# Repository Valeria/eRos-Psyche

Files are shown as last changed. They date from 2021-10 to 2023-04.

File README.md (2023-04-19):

# eRos & Psyche
### **Open Source Dildo running on the ESP32 Platform**

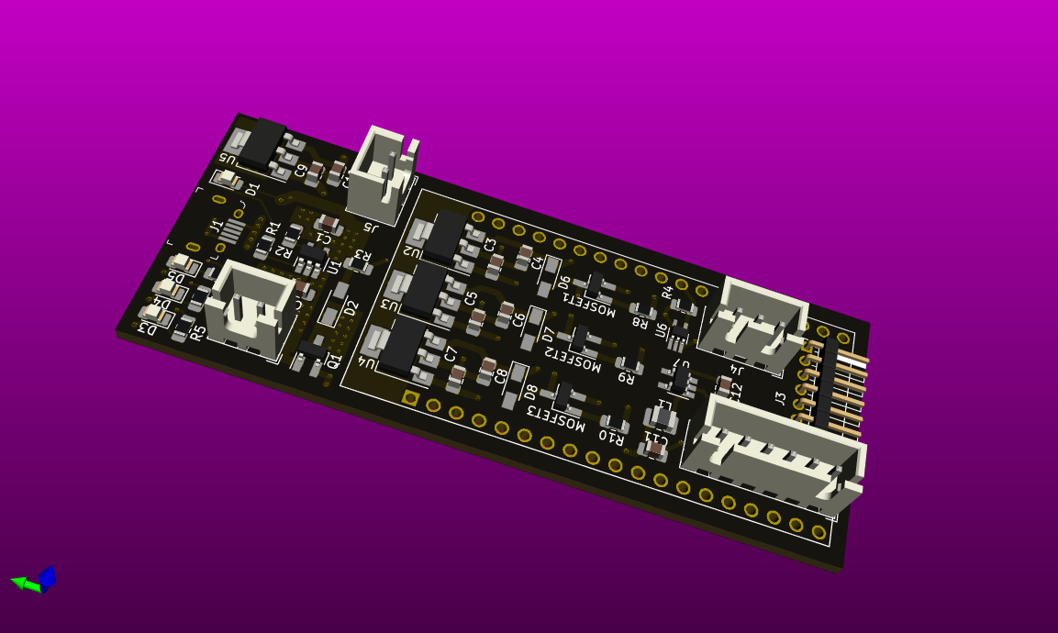
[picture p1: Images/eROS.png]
PCB! PCB

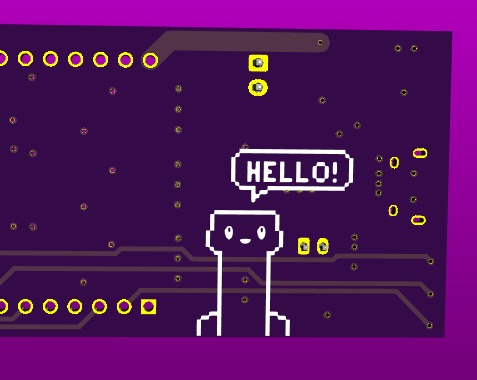
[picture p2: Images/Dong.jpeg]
Hello! Hi!

Licenses License Information

V1.0 Attaches to a **ESP32-DevKitC-V4**, **check pinout to make sure it coincides**.

It's meant to drive three (or less) **3.3v motors, max 1A per PWM output**.
Use with Li-Po or Li-Ion **3.7v nominal voltage batteries**.

Connects to a **Blynk.io** server, which can be self-hosted, otherwise, use the free Blynk Cloud server or contact me for a spot on mine.

Mobile app can be recreated by scanning the following QR code on the Blynk phone app:

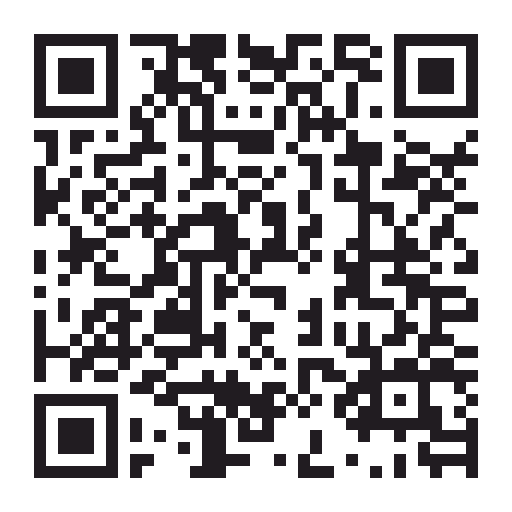
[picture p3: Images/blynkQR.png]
Blynk Project QR Scan this on Blynk app


Hardware files are in the **eRos** directory, meant to be edited on **KiCad v5.0 or higher**.

Firmware files are in the **Psyche** directory, if you open the project on PlatformIO it should load all required Arduino libraries automatically, else, here's a list:

 - shaggydog/OneButton@^1.5.0
 - ayushsharma82/AsyncElegantOTA@^2.2.5
 - ottowinter/AsyncTCP-esphome@^1.2.1
 - ottowinter/ESPAsyncWebServer-esphome@^1.2.7
 - bblanchon/ArduinoJson@^6.17.3
 - s00500/ESPUI@^2.0.0
 - khoih.prog/Blynk_Async_ESP32_BT_WF@^1.2.1
 - adafruit/Adafruit BMP280 Library@^2.4.1
 - teckel12/NewPing@^1.9.1
 - gamegine/HCSR04 ultrasonic sensor@^2.0.2
 - adafruit/Adafruit_VL53L0X@^1.1.1

Firmware.bin must be built with the **huge_app.csv** partition scheme.

Have fun!

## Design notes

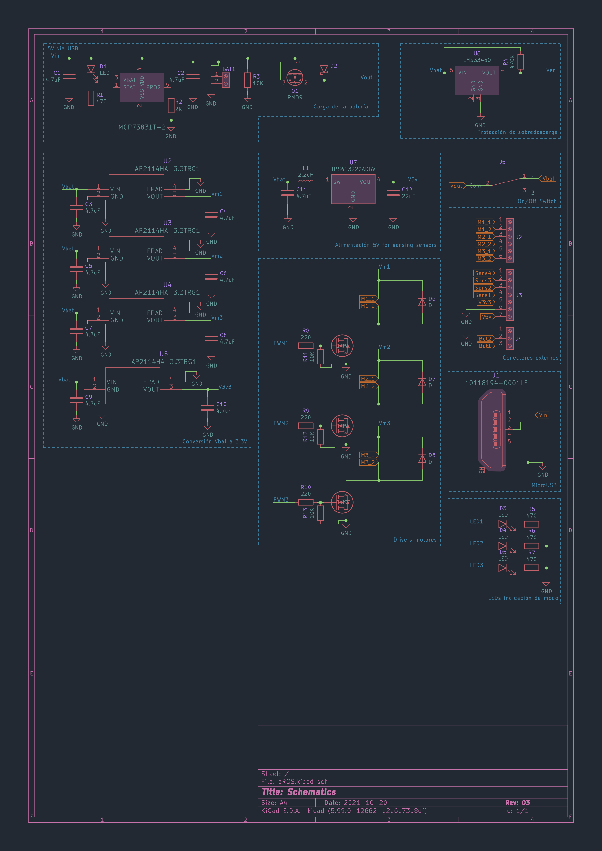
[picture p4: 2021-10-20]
Images/Schematics.png

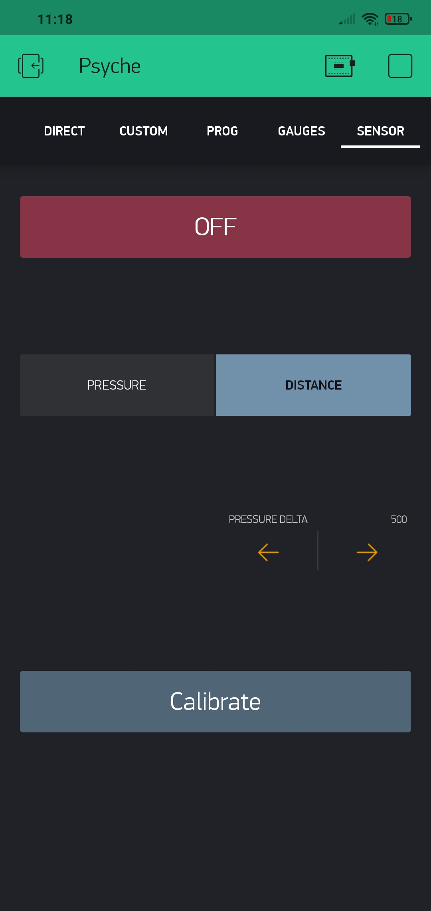
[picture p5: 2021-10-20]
Images/blynkSensor.jpg

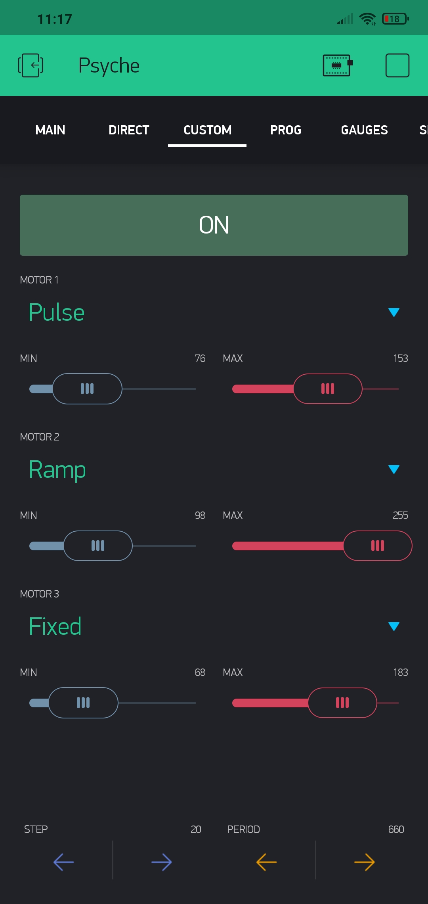
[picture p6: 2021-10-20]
Images/blynkCustom.jpg

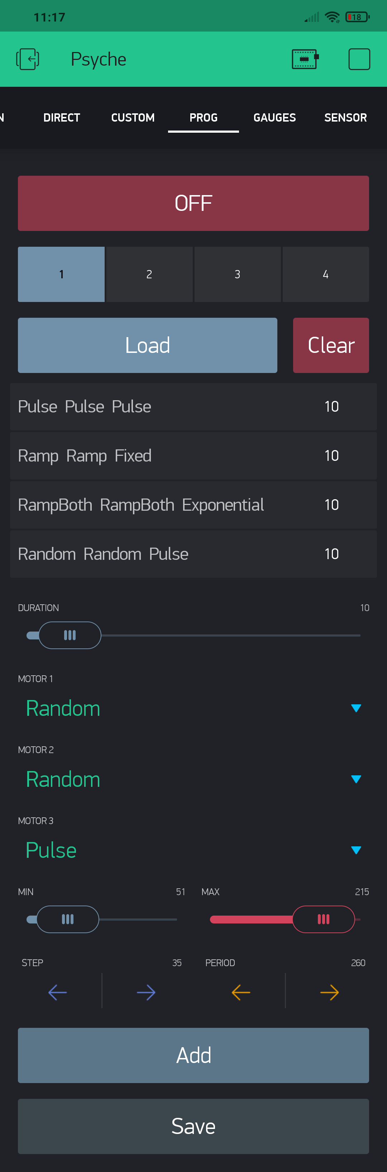
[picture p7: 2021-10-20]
Images/blynkProg.png

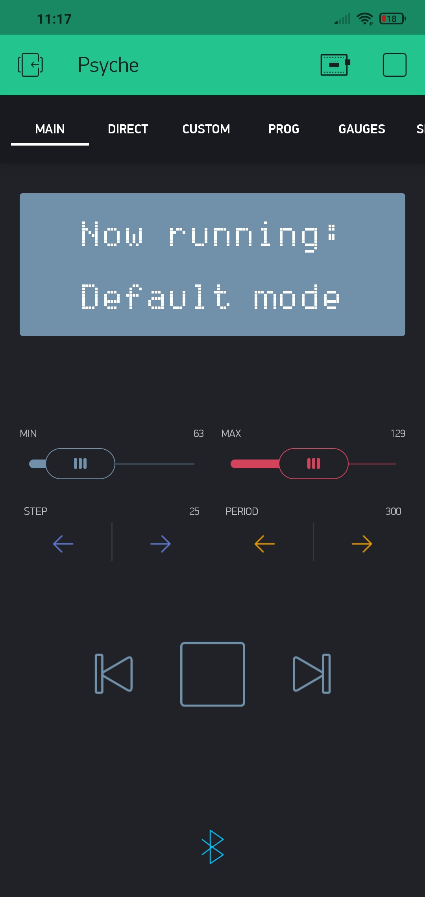
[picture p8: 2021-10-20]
Images/blynkMain.jpg

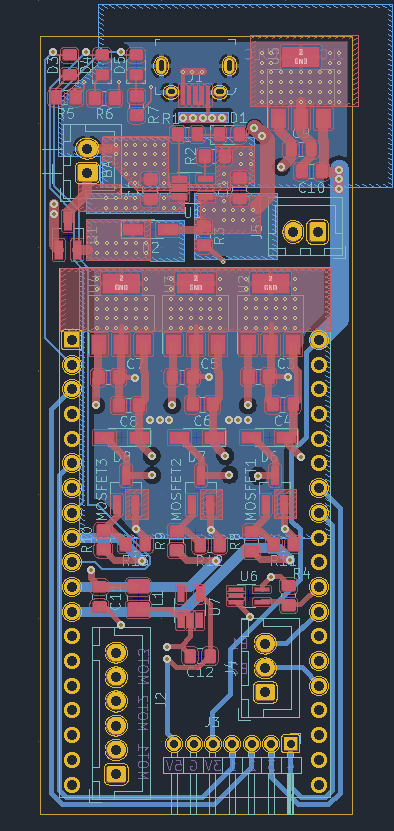
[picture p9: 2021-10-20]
Images/PCB.png

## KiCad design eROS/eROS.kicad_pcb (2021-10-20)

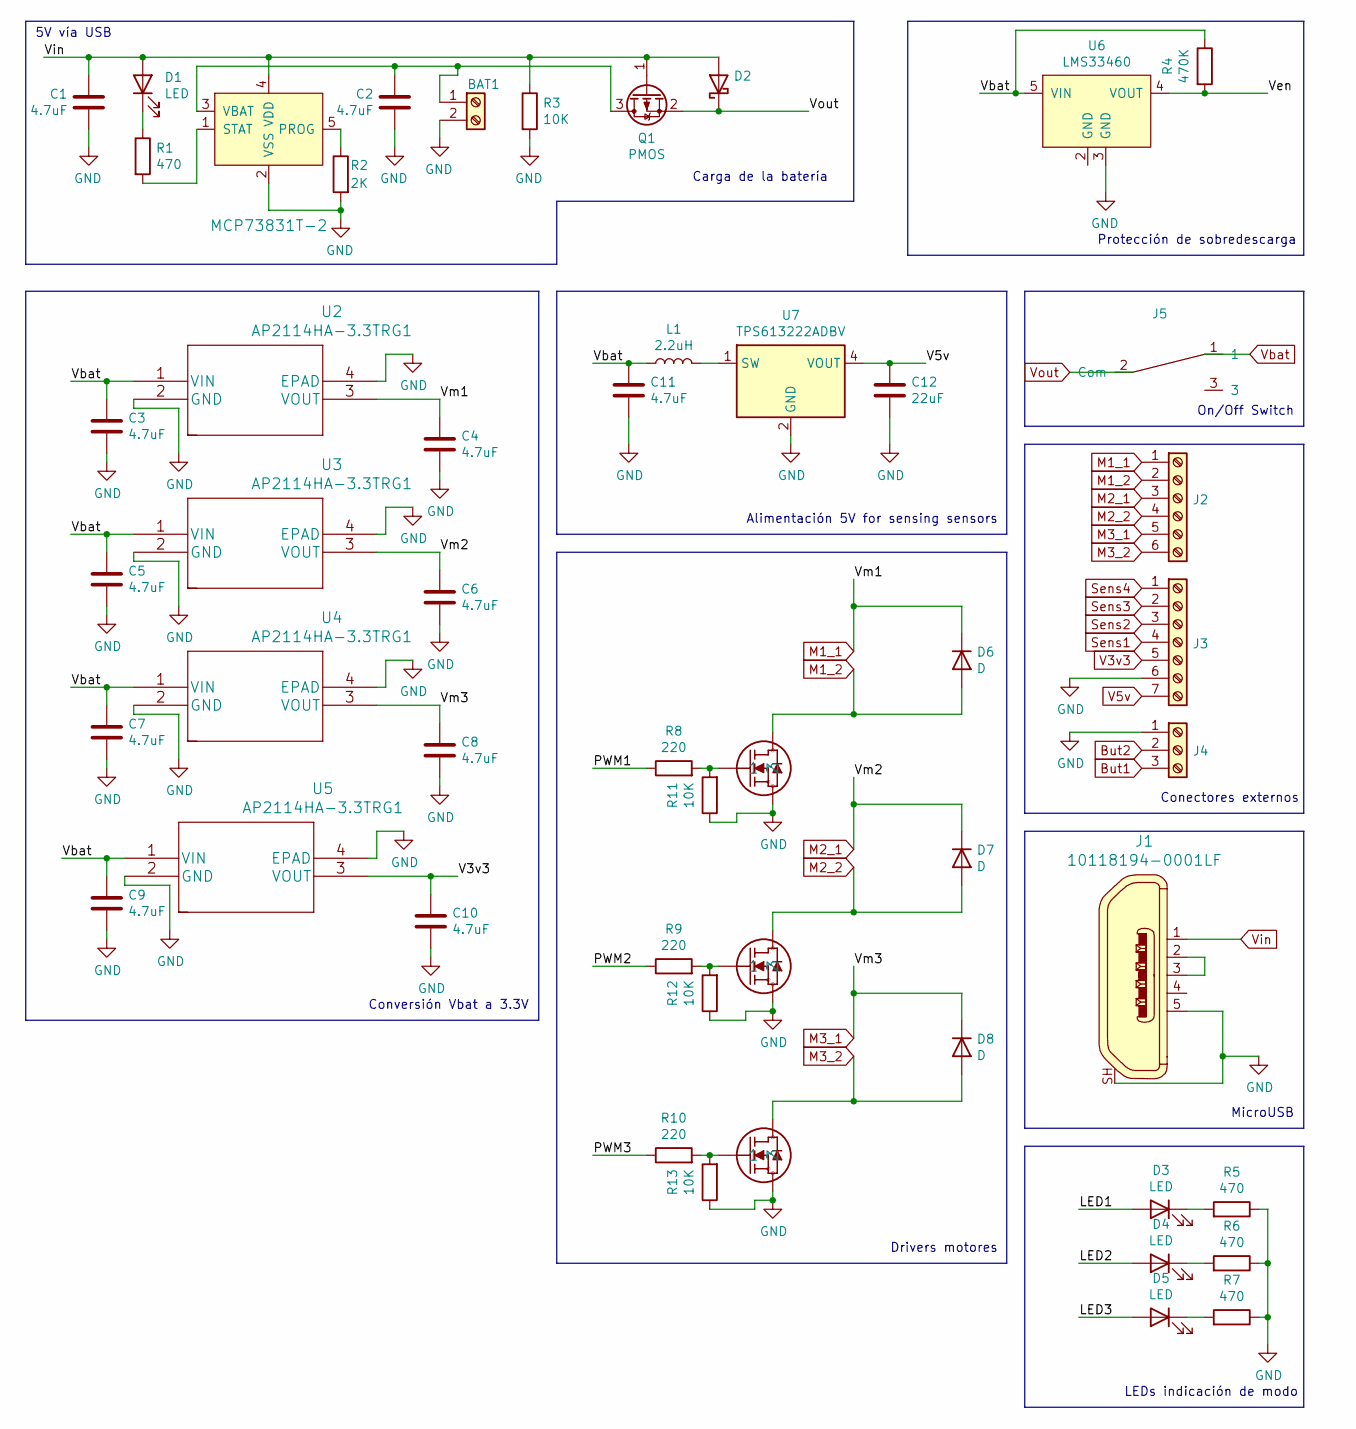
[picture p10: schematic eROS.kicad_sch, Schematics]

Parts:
BAT1: Screw_Terminal_01x02; JST_XH_B2B-XH-A_1x02_P2.50mm_Vertical
C1, C2, C3, C4, C5, C6, C7, C8, C9, C10, C11: 4.7uF; C_0805_2012Metric_Pad1.18x1.45mm_HandSolder
C12: 22uF; C_0805_2012Metric_Pad1.18x1.45mm_HandSolder
D1, D3, D4, D5: LED; LED_0805_2012Metric_Pad1.15x1.40mm_HandSolder
D2: D_Schottky; Nexperia_CFP3_SOD-123W_Handsolder
D6, D7, D8: D; Nexperia_CFP3_SOD-123W_Handsolder
J1: 10118194-0001LF; USB_Micro_B_Female_10118194-0001LF_HandSolder; MPN 10118194-0001LF; Digi-Key_PN 609-4618-1-ND
J2: Screw_Terminal_01x06; JST_XH_B6B-XH-A_1x06_P2.50mm_Vertical
J3: Screw_Terminal_01x07; PinHeader_1x07_P2.00mm_Horizontal
J4: Screw_Terminal_01x03; JST_XH_B3B-XH-A_1x03_P2.50mm_Vertical
J5: MiniSlideSwitch; JST_XH_B2B-XH-A_1x02_P2.50mm_Vertical
L1: 2.2uH; L_1008_2520Metric_Pad1.43x2.20mm_HandSolder
MOSFET1, MOSFET2, MOSFET3: IRLML6246TRPBF; SOT-23_Handsoldering
Q1: PMOS; SOT-23_Handsoldering
R1, R5, R6, R7: 470; R_0805_2012Metric_Pad1.20x1.40mm_HandSolder
R2: 2K; R_0805_2012Metric_Pad1.20x1.40mm_HandSolder
R3, R11, R12, R13: 10K; R_0805_2012Metric_Pad1.20x1.40mm_HandSolder
R4: 470K; R_0805_2012Metric_Pad1.20x1.40mm_HandSolder
R8, R9, R10: 220; R_0805_2012Metric_Pad1.20x1.40mm_HandSolder
U1: MCP73831T-2; SOT-23-5_HandSoldering; MPN MCP73831T-2DCI/OT; Digi-Key_PN MCP73831T-2DCI/OTCT-ND
U2, U3, U4, U5: AP2114HA-3.3TRG1; SOT-223-3_TabPin2
U6: LMS33460; SOT-353_SC-70-5_Handsoldering; mpn LMS33460
U7: TPS613222ADBV; SOT-23-5_HandSoldering

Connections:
/LED1: D3.2 (A)
/LED2: D4.2 (A)
/LED3: D5.2 (A)
/PWM1: R8.1
/PWM2: R9.1
/PWM3: R10.1
/Ven: R4.2, U6.4 (VOUT)
But1: J4.3
But2: J4.2
GND: BAT1.2, C1.2, C2.2, C3.2, C4.2, C5.2, C6.2, C7.2, C8.2, C9.2, C10.2, C11.2, C12.2, J1.5, J1.SH, J3.6, J4.1, MOSFET1.2, MOSFET2.2, MOSFET3.2, R2.2, R3.2, R5.1, R6.1, R7.1, R11.1, R12.1, R13.1, U1.2 (VSS), U2.2 (GND), U2.4 (EPAD), U3.2 (GND), U3.4 (EPAD), U4.2 (GND), U4.4 (EPAD), U5.2 (GND), U5.4 (EPAD), U6.3 (GND), U7.2 (GND)
M1_1: C4.1, D6.1 (K), J2.1, U2.3 (VOUT)
M1_2: D6.2 (A), J2.2, MOSFET1.3
M2_1: C6.1, D7.1 (K), J2.3, U3.3 (VOUT)
M2_2: D7.2 (A), J2.4, MOSFET2.3
M3_1: C8.1, D8.1 (K), J2.5, U4.3 (VOUT)
M3_2: D8.2 (A), J2.6, MOSFET3.3
unnamed: BAT1.1, C2.1, Q1.3 (D), U1.3 (VBAT)
unnamed: D1.1 (K), R1.1
unnamed: D3.1 (K), R5.2
unnamed: D4.1 (K), R6.2
unnamed: D5.1 (K), R7.2
unnamed: J1.2, J1.3
unnamed: L1.2, U7.1 (SW)
unnamed: MOSFET1.1, R8.2, R11.2
unnamed: MOSFET2.1, R9.2, R12.2
unnamed: MOSFET3.1, R10.2, R13.2
unnamed: R1.2, U1.1 (STAT)
unnamed: R2.1, U1.5 (PROG)
Sens1: J3.4
Sens2: J3.3
Sens3: J3.2
Sens4: J3.1
V3v3: C10.1, J3.5, U5.3 (VOUT)
V5v: C12.1, J3.7, U7.4 (VOUT)
Vbat: C3.1, C5.1, C7.1, C9.1, C11.1, J5.1, L1.1, R4.1, U2.1 (VIN), U3.1 (VIN), U4.1 (VIN), U5.1 (VIN), U6.5 (VIN)
Vin: C1.1, D1.2 (A), D2.2 (A), J1.1, Q1.1 (G), R3.1, U1.4 (VDD)
Vout: D2.1 (K), J5.2 (Com), Q1.2 (S)

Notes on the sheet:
5V vía USB
Conversión Vbat a 3.3V
Carga de la batería
Alimentación 5V for sensing sensors
Drivers motores
Protección de sobredescarga
LEDs indicación de modo
Conectores externos
On/Off Switch
MicroUSB

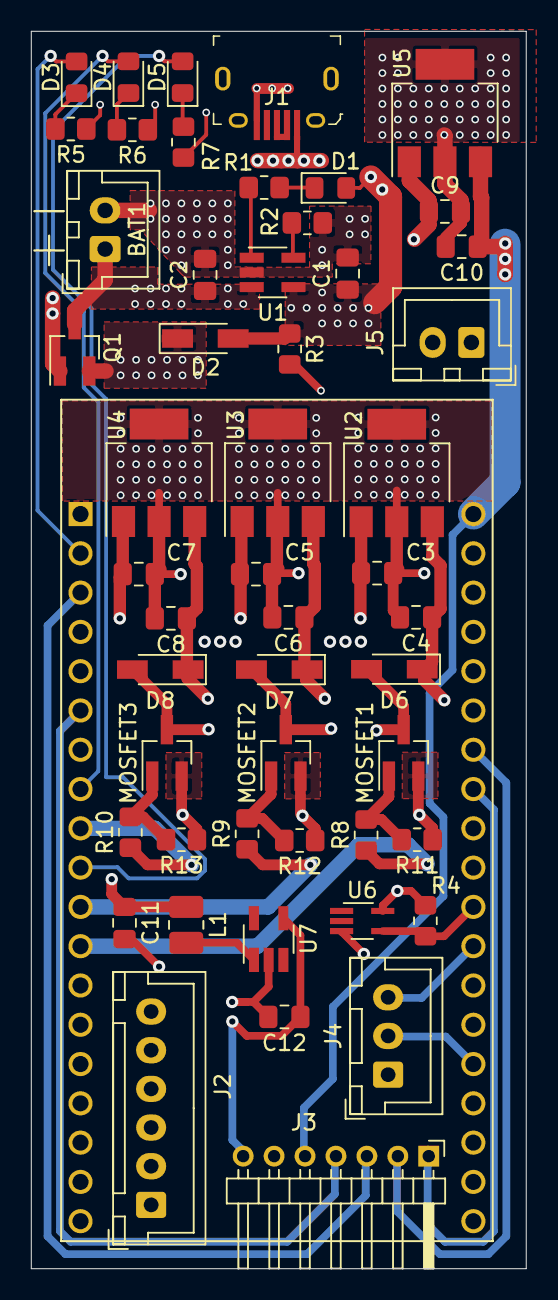
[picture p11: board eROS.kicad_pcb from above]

Board: 4 copper layers, 32.0 x 80.0 mm, 51 parts (0 on the bottom side), 25 nets.

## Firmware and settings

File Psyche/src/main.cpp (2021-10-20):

/********************************************************
  
  Based on code examples built by Khoi Hoang
  https://github.com/khoih-prog/Blynk_Async_ESP32_BT_WF
  which are licensed under MIT license.
     
 *******************************************************/

#include "defines.h"
#include "Credentials.h"
#include "dynamicParams.h"
#include "Arduino.h"
#include "OneButton.h"
#include "ArduinoJson.h"
#include "FS.h"
#include "SPIFFS.h"
#include "Adafruit_BMP280.h"
#include "Wire.h"
//#include "NewPing.h"
//#include <HCSR04.h>
#include "Adafruit_VL53L0X.h"

Adafruit_VL53L0X lox = Adafruit_VL53L0X();

// Setup Buttons
OneButton button1(14, true, true);
OneButton button2(13, true, true);

// LEDs
const int led[3] = {5, 19, 23};

// Sensors
const int sensor[4] = {21, 22, 32, 33};

// Ven: low battery signal

#define vEnableEnabled false // Enables the usage of the undervoltage detector
const int Ven = 27;
const int trytry = 0;

// PWM integers
int freq = 10000; // 10 Khz
int motorChannel[3] = {0, 1, 2};
int resolution = 8;                // 2^8 = 256 possible values
const int motor[3] = {16, 17, 18}; // Motors GPIO

// Pattern integers
int next = 0;
int lastNext = 1;
int vmax = 200;
int vmin = 30;
int step = 25;
char vminC[3], vmaxC[3], nextC[3], stepC[3], periodC[3]; // Will be required for Blynk LCD Widget
unsigned long period = 250;
unsigned long currentTime = 0;
unsigned long lastTime = 0;
int seq = 0;
int seq2 = 0;
int now = 0;

// Blynk custom pattern integers
int customMode = 0;
unsigned long lastTimeCustom[3] = {0, 0, 0};
unsigned long currentTimeCustom[3] = {0, 0, 0};
unsigned long stepCustom = 25;
unsigned long periodCustom = 200;
int vminCustom[3] = {30, 30, 30};
int vmaxCustom[3] = {255, 255, 255};
int nowCustom[3] = {0, 0, 0};
int nextCustom[3] = {0, 0, 0};
int seqCustom[3] = {0, 0, 0};
int seq2Custom[3] = {0, 0, 0};
int kCustom[3] = {1, 1, 1};

// Blynk sensor mode integers
int sensorMode = 0; // Are we in sensor mode?
int x, y, z = 0;    // We be floating in space (Gravity sensor integers)

// Blynk direct control integers
int directControl = 0; // Are we being direct controlled? (Can't assume this)
int sliderjoy = 1;     // Assume direct control via sliders (1) or joystick (2).
int joyX = 0;
int joyY = 0;

// Patterns list
#include <patterns.h>
int maxpatterns = 6; // Number of actual patterns used

// Function to set motor PWM settings to correct pattern values
// also a list of patterns currently in use
void callPattern(int k)
{
  switch (k)
  {
  case 0:
    fixedAll(0);
    break;
  case 1:
    fixedAll(vmax);
    break;
  case 2:
    pulse(vmin, vmax);
    break;
  case 3:
    ramp(vmin, vmax, step);
    break;
  case 4:
    rampBoth(vmin, vmax, step);
    break;
  case 5:
    sharpRamp(seq);
    break;
  case 6:
    randi(vmin, vmax);
    break;
  default:
    break;
  }
}

// Will be called when Button1 is clicked a single time
void Click1()
{
  next += 1;
  if (next > maxpatterns)
    next = 1; // Loop back if over range
} // Click1

// Will be called when Button2 is clicked a single time.
void Click2()
{
  next -= 1;
  if (next < 1)
    next = maxpatterns; // Loop back if over range
} // Click2

// Will be called when Button1 is held.
void HODL1()
{
  if (digitalRead(13) == LOW)
    next = 0;
} // HODL1

// Will be called when Button2 is held.
void HODL2()
{
  if (digitalRead(14) == LOW)
    next = 0;
} // HODL2

// Will be called when Button1 is clicked twice.
void ClickDouble1()
{
  vmax += 25;
  vmax = constrain(vmax, vmin, 255);
  //callPattern(next);
} // ClickDouble1

// Will be called when Button2 is clicked twice.
void ClickDouble2()
{
  vmax -= 25;
  vmax = constrain(vmax, vmin, 255);
  //callPattern(next);
} // ClickDouble2

bool USE_BLE = true;
long timePreviousMeassure = 0;

#include "blynk.h"
#include "table.h"

#define WIFI_BLE_SELECTION_PIN 14 //Pin D14 mapped to pin GPIO14/HSPI_SCK/ADC16/TOUCH6/TMS of ESP32

BlynkTimer timer;

#include <Ticker.h>
Ticker led_ticker;

#define BLYNK_PIN_FORCED_CONFIG V100 // Pin to access web configuration portal

#include <asyncSetup.h>
#include "sensor.h"

void setup()
{
  // Initialize PWM
  ledcSetup(motorChannel[0], freq, resolution);
  ledcAttachPin(motor[0], motorChannel[0]);
  ledcSetup(motorChannel[1], freq, resolution);
  ledcAttachPin(motor[1], motorChannel[1]);
  ledcSetup(motorChannel[2], freq, resolution);
  ledcAttachPin(motor[2], motorChannel[2]);

  ledcWrite(motorChannel[0], 0);
  ledcWrite(motorChannel[1], 0);
  ledcWrite(motorChannel[2], 0);

  // Initialize serial console
  Serial.begin(115200);
  /*while (!Serial)
    ;

  //delay(200);
  */

  setCpuFrequencyMhz(80); // To lower power usage, default 240Mhz isn't required for this application

  SPIFFS.begin();

  pinMode(WIFI_BLE_SELECTION_PIN, INPUT_PULLUP);
  //pinMode(WIFI_BLE_SELECTION_PIN, INPUT);

  // Set Timer to update gauges
  gaugeTimer.setInterval(1000L, gauges);

  // LEDs
  //pinMode(led[1], OUTPUT);
  //pinMode(led[2], OUTPUT);
  //pinMode(led[3], OUTPUT);

  // Sensors
  //pinMode(sensor[1], OUTPUT);
  //pinMode(sensor[2], INPUT);
  //pinMode(sensor[3], INPUT);
  //pinMode(sensor[4], INPUT); //Commented out for usage as capacitive pin

  // Ven: low battery signal
  pinMode(Ven, INPUT);

  // Attach button clicks to functions
  button1.attachClick(Click1);
  button1.attachDoubleClick(ClickDouble1);
  button1.attachLongPressStart(HODL1);
  button2.attachClick(Click2);
  button2.attachDoubleClick(ClickDouble2);
  button2.attachLongPressStart(HODL2);

// Pressure sensor
/*#if sensorsEnabled
  bmpSetup();
#endif
*/

#if BLYNK_USE_BLE_ONLY
  Blynk_BLE.setDeviceName(BLE_Device_Name);

#if ESP32_BLE_WF_DEBUG
  Serial.println(F("Blynk_BLE begin"));
#endif

  Blynk_BLE.begin(auth);
#else
  //if (digitalRead(WIFI_BLE_SELECTION_PIN) == HIGH)
    if (trytry == 1)
  {
    USE_BLE = false;
    Serial.println(F("Using Wi-Fi"));
#if USE_BLYNK_WM
    // Set config portal SSID and Password
    Blynk.setConfigPortal("eRos-ConfigPortal", "123456789");
    // Set config portal IP address
    Blynk.setConfigPortalIP(IPAddress(192, 168, 232, 1));

    // Set config portal channel, default = 1. Use 0 => random channel from 1-13 to avoid conflict
    Blynk_WF.setConfigPortalChannel(0);

    // Set static IP + DNS
    Blynk.setSTAStaticIPConfig(IPAddress(192, 168, 2, 232), IPAddress(192, 168, 2, 1), IPAddress(255, 255, 255, 0));

#if USING_CUSTOMS_STYLE
    Blynk.setCustomsStyle(NewCustomsStyle);
#endif

#if USING_CUSTOMS_HEAD_ELEMENT
    Blynk.setCustomsHeadElement("<style>html{filter: invert(10%);}</style>");
#endif

#if USING_CORS_FEATURE
    Blynk.setCORSHeader("Your Access-Control-Allow-Origin");
#endif

    //////////////////////////////////////////////

    // Use this to default DHCP hostname to ESP8266-XXXXXX or ESP32-XXXXXX
    //Blynk.begin();
    // Use this to personalize DHCP hostname (RFC952 conformed)
    // 24 chars max,- only a..z A..Z 0..9 '-' and no '-' as last char
    //Blynk.begin("ESP32-BLE-WM");

    Blynk_WF.begin(BLE_Device_Name);
#else
    //Blynk_WF.begin(auth, ssid, pass);
#if ESP32_BLE_WF_DEBUG
    Serial.println(F("Not USE_BLYNK_WM: Blynk_WF begin"));
#endif
    Blynk_WF.begin(auth, ssid, pass, cloudBlynkServer.c_str(), BLYNK_SERVER_HARDWARE_PORT);
#endif
  }
  else
  {
    USE_BLE = true;
    Serial.println(F("Using BLE"));
    Blynk_BLE.setDeviceName(BLE_Device_Name);
#if USE_BLYNK_WM
    if (Blynk_WF.getBlynkBLEToken() == NO_CONFIG) //String("blank"))
    {
      Serial.println(F("No valid stored BLE auth. Must run WiFi and enter config portal"));
      USE_BLE = false;

#if ESP32_BLE_WF_DEBUG
      Serial.println(F("USE_BLYNK_WM: No BLE Token. Blynk_WF begin"));
#endif

      Blynk_WF.begin(BLE_Device_Name);
    }
    String BLE_auth = Blynk_WF.getBlynkBLEToken();
#else
    String BLE_auth = auth;
#endif

    if (USE_BLE)
    {
      Serial.print(F("Connecting Blynk via BLE, using auth = "));
      Serial.println(BLE_auth);

#if ESP32_BLE_WF_DEBUG
      Serial.println(F("USE_BLE: Blynk_BLE begin"));
#endif

      Blynk_BLE.begin(BLE_auth.c_str());
    }
  }
#endif

  // Important, need to keep constant communication to Blynk Server at least once per ~25s
  // Or Blynk will lost and have to (auto)reconnect
  timer.setInterval(10000L, noticeAlive);

  /*
  if (!lox.begin()) {
    Serial.println(F("Failed to boot VL53L0X"));
  }
  */
 Wire.begin(32, 33);
}

#if (USE_BLYNK_WM && USE_DYNAMIC_PARAMETERS)
void displayCredentials()
{
  Serial.println(F("\nYour stored Credentials :"));

  for (uint16_t i = 0; i < NUM_MENU_ITEMS; i++)
  {
    Serial.print(myMenuItems[i].displayName);
    Serial.print(F(" = "));
    Serial.println(myMenuItems[i].pdata);
  }
}

void displayCredentialsInLoop()
{
  static bool displayedCredentials = false;

  if (!displayedCredentials)
  {
    for (uint16_t i = 0; i < NUM_MENU_ITEMS; i++)
    {
      if (!strlen(myMenuItems[i].pdata))
      {
        break;
      }

      if (i == (NUM_MENU_ITEMS - 1))
      {
        displayedCredentials = true;
        displayCredentials();
      }
    }
  }
}

#endif

void loop()
{
#if vEnableEnabled
  while (digitalRead(Ven) == LOW) // Do nothing until we get high voltage signal
    ;
#endif
  // Keep checking the buttons
  //button1.tick();
  //button2.tick();

#if BLYNK_USE_BLE_ONLY
  Blynk_BLE.run();
#else
  if (USE_BLE)
    Blynk_BLE.run();
  else
    Blynk_WF.run();
#endif

  // Call function to update PWM values
  if (directControl)
  {
    // We do nothin'!
  }
  else if (customMode)
  {
    callPatternCustom(kCustom[0], 0);
    callPatternCustom(kCustom[1], 1);
    callPatternCustom(kCustom[2], 2);
  }
  else if (tableMode)
  {
    nextTable();                            // Checks if we must move to the next pattern in the list
    callTable(patternList1[indexTable], 0); // Sets motors
    callTable(patternList2[indexTable], 1);
    callTable(patternList3[indexTable], 2);
  }
  else if (sensorMode)
  {
    if (sensorSelect == 1)
      sonarPattern();
    else if (sensorSelect == 2)
      bmpPattern();
    else if (sensorSelect == 3)
      capacitive();
  }
  else
    callPattern(next);

  timer.run();
  checkStatus();
  gaugeTimer.run();

#if (USE_BLYNK_WM && USE_DYNAMIC_PARAMETERS)
  displayCredentialsInLoop();
#endif
}

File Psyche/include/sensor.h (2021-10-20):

#define sensorsEnabled true
unsigned int sensorSelect = 0;
int capacitiveVal = 100;
int capacitiveThreshold = 2;
int sensorDone = 0;

// ESP32 Capacitive touch sensor

void capacitive()
{
currentTime = millis();
    if (currentTime - lastTime >= 100)
    {
        lastTime = currentTime;
        capacitiveVal = touchRead(T8); // GPIO 33
        if (capacitiveVal < capacitiveThreshold)
        {
            ledcWrite(motorChannel[0], vmax);
            ledcWrite(motorChannel[1], vmax);
            ledcWrite(motorChannel[2], vmax);
        }
        else
        {
            ledcWrite(motorChannel[0], vmin);
            ledcWrite(motorChannel[1], vmin);
            ledcWrite(motorChannel[2], vmin);
        }
        lcd.print(4, 0, capacitiveVal);
    }
}
// BMP280 Pressure, temperature sensor
Adafruit_BMP280 bmp; // use I2C interface
Adafruit_Sensor *bmp_temp = bmp.getTemperatureSensor();
Adafruit_Sensor *bmp_pressure = bmp.getPressureSensor();
float pressure = 0;
float pressureOffset = 0;
float pressureDelta = 500;

void bmpSetup()
{
    bmp.begin();

    /* Default settings from datasheet. */
    bmp.setSampling(Adafruit_BMP280::MODE_NORMAL,     /* Operating Mode. */
                    Adafruit_BMP280::SAMPLING_X2,     /* Temp. oversampling */
                    Adafruit_BMP280::SAMPLING_X16,    /* Pressure oversampling */
                    Adafruit_BMP280::FILTER_X16,      /* Filtering. */
                    Adafruit_BMP280::STANDBY_MS_500); /* Standby time. */
}

void bmpPattern()
{
    pressure = bmp.readPressure();
    if (pressure - pressureOffset >= pressureDelta)
    {
        ledcWrite(motorChannel[0], vmax);
        ledcWrite(motorChannel[1], vmax);
        ledcWrite(motorChannel[2], vmax);
    }
    else
    {
        ledcWrite(motorChannel[0], vmin);
        ledcWrite(motorChannel[1], vmin);
        ledcWrite(motorChannel[2], vmin);
    }
}

// HC-SR04 Ultrasonic distance sensor
int maxDistance = 50;
//NewPing sonar(32, 33, maxDistance); // Trigger GPIO 21, Echo GPIO 22, 50cm max distance
//HCSR04 hc(32, 33);
int distance = 0;
VL53L0X_RangingMeasurementData_t measure;

void sonarPattern()
{
    delay(100); // Wait some time between pings
    lox.rangingTest(&measure, false); // pass in 'true' to get debug data printout!

    if (measure.RangeStatus != 4) {  // phase failures have incorrect data
    distance = measure.RangeMilliMeter;
    }
    //distance = sonar.ping_cm();
    //distance = hc.dist();
    
    if (distance > 500 || distance == 0)
    {
        ledcWrite(motorChannel[0], 0);
        ledcWrite(motorChannel[1], 0);
        ledcWrite(motorChannel[2], 0);
    }
    if (distance >= 400 && distance <= 500)
    {
        ledcWrite(motorChannel[0], 50);
        ledcWrite(motorChannel[1], 50);
        ledcWrite(motorChannel[2], 50);
    }
    else if (distance >= 300 && distance < 400)
    {
        ledcWrite(motorChannel[0], 100);
        ledcWrite(motorChannel[1], 100);
        ledcWrite(motorChannel[2], 100);
    }
    else if (distance >= 200 && distance < 300)
    {
        ledcWrite(motorChannel[0], 150);
        ledcWrite(motorChannel[1], 150);
        ledcWrite(motorChannel[2], 150);
    }
    else if (distance >= 100 && distance < 200)
    {
        ledcWrite(motorChannel[0], 200);
        ledcWrite(motorChannel[1], 200);
        ledcWrite(motorChannel[2], 200);
    }
    else if (distance < 100 && distance > 10)
    {
        ledcWrite(motorChannel[0], 255);
        ledcWrite(motorChannel[1], 255);
        ledcWrite(motorChannel[2], 255);
    }
    Serial.println(distance);
}

BLYNK_WRITE(V60)
{
    sensorMode = param.asInt();
    if (sensorMode == 1 && sensorDone == 0)
    {
    if (!lox.begin()) {
    Serial.println(F("Failed to boot VL53L0X"));
    sensorDone = 1;
    }
    }
}
BLYNK_WRITE(V61)
{
    sensorSelect = param.asInt();
}
BLYNK_WRITE(V62)
{
    if (param.asInt())
        pressureOffset = bmp.readPressure();
}
BLYNK_WRITE(V63)
{
    pressureDelta = param.asInt();
}

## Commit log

2021-10-20 KiCad Hardware files added
    [eROS.kicad_pcb, eROS.kicad_sch, eROS.sch]
2021-10-20 Schematics/PCB images
2021-10-20 PlatformIO (or Arduino editor) Firmware files
2021-10-20 PCB 3D Render
